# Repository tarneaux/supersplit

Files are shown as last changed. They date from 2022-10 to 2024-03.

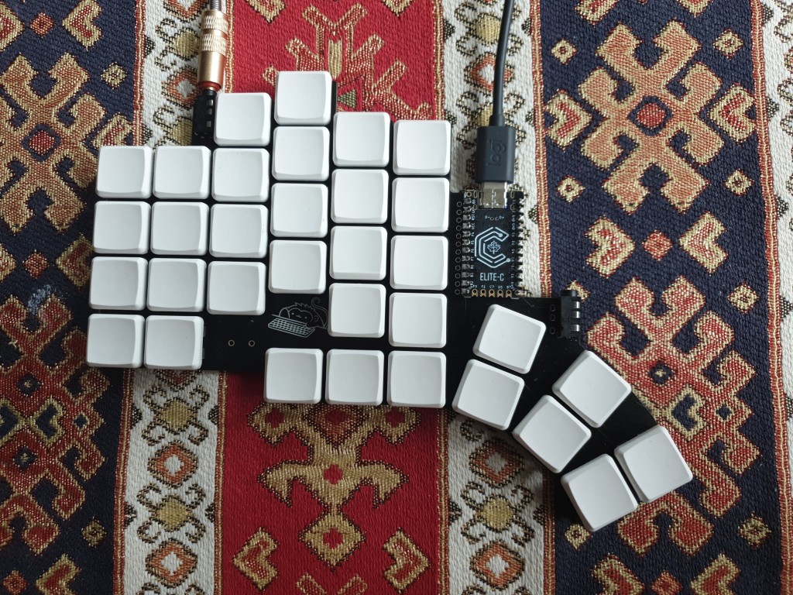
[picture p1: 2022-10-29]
photo.jpg

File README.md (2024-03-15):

# supersplit

You can read the article about this [here](https://tarneo.fr/posts/split_keyboard).

## What is this?
I tried to make a keyboard that is easy to use and compact. For this it has an (oversized) 9-key thumbfan and a (non-oversized) 4x6 matrix.

the entire keyboard

## Features
- 9-key thumbfan
- 4x6 matrix
- 2 trrs jacks on each side (four in total) for flexibility: on each side you can choose which one to use
- 2 elite-c controllers -> usb-c

## Downsides of this layout
As soon as I had soldered the keyboard, I noticed that the 4 outer thumb keys (On the right on the picture) were hard to reach and I am still not using them after a month of using this keyboard.
The 2 that are just next to the thumb home (the next 2 on the left of the previous) are easier to use but I prefer to use the 2 inner.
In short, that means I could have saved 6 keys on each side's thumfan.

## What I would do differently
I would let the matrix as is, remove the 4 outer thumfan keys and add a few degrees to the angle added to the next 2.

## Disclaimer

This was my first attempt at making my own PCB based split keyboard. The result didn't turn out great for this one, but I made a new keyboard I find much better to use, the [Triboard](https://github.com/tarneaux/triboard).

This keyboard has far too many keys on the thumbfan: the three keys below the matrix are easy to reach, but others are not: you could train your muscles to reach for the one a bit more to the middle, but the five others are just superfluous. If you really want that many keys in a keyboard:
- You don't need that many keys. They are useless. Really.
- If you still want a keywell so large, at least put it closer to your wrist and increase the angle compared to the keyboard. Then, use MX switches instead of choc ones to make the outer key well easier to reach.

You have been warned.

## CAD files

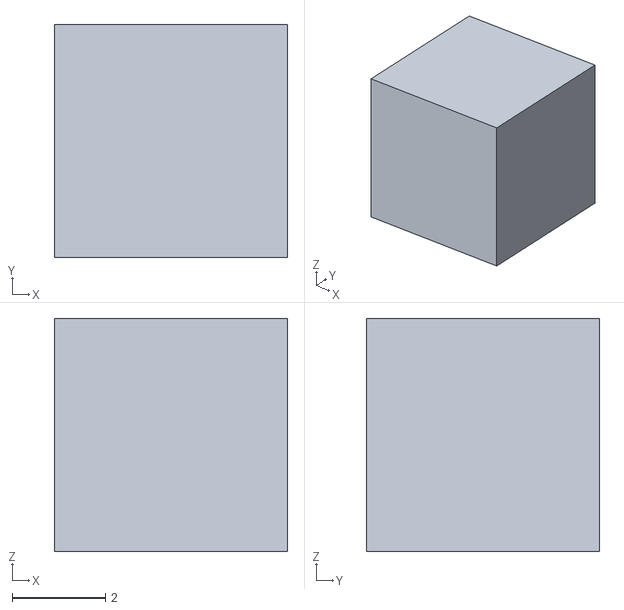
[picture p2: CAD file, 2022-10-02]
ergogen/test/cases/001_cube___cases_cube_stl.stl
5.00 x 5.00 x 5.00

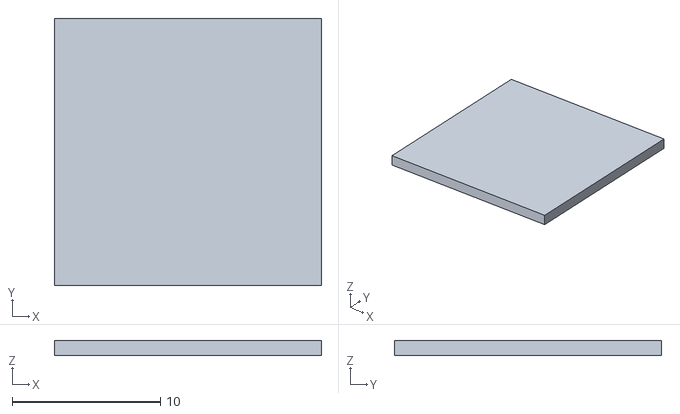
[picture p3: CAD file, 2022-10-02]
ergogen/test/cli/big/reference/cases/_export.stl
18.0 x 18.0 x 1.00

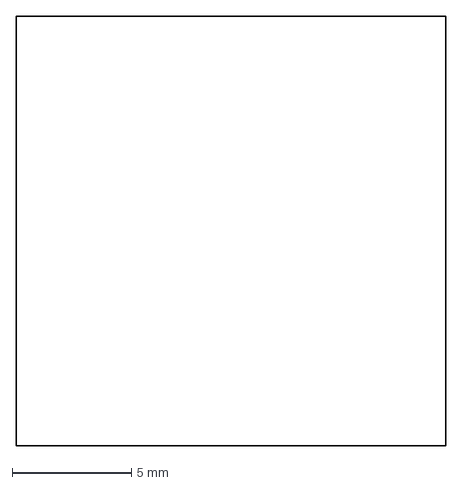
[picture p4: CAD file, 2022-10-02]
ergogen/test/cli/big/reference/outlines/_export.dxf
18.0 x 18.0 mm

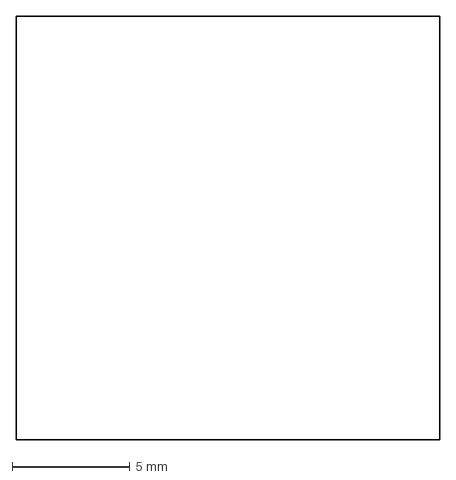
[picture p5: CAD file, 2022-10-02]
ergogen/test/cli/big/reference/points/demo.dxf
18.0 x 18.0 mm

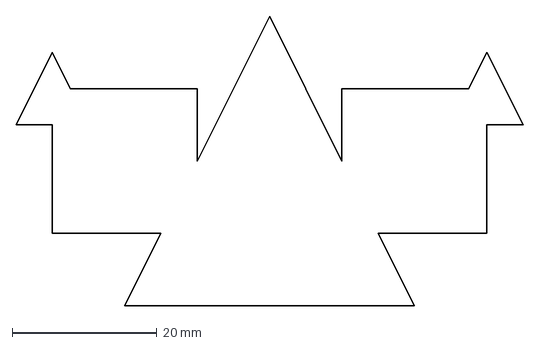
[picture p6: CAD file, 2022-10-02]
ergogen/test/outlines/polygons___outlines_outline_dxf.dxf
70.0 x 40.0 mm

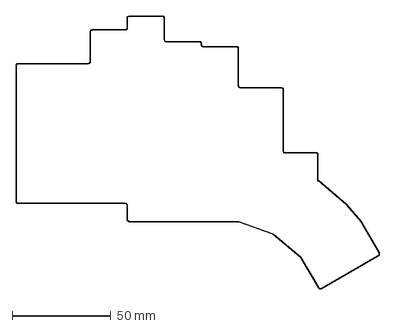
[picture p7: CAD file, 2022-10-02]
output/outlines/pcb.dxf
183.8 x 138.0 mm

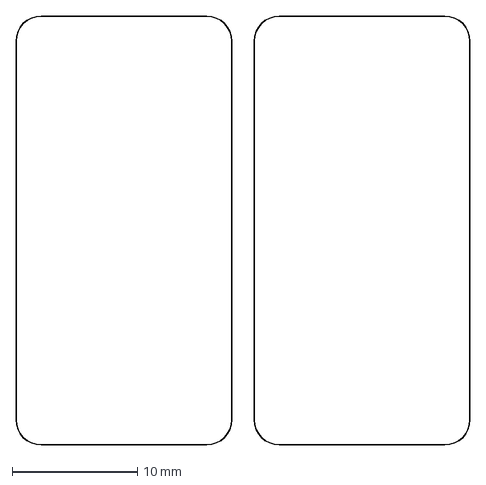
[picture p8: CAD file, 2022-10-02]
ergogen/test/outlines/fillet___outlines_fillet_dxf.dxf
36.2 x 34.2 mm

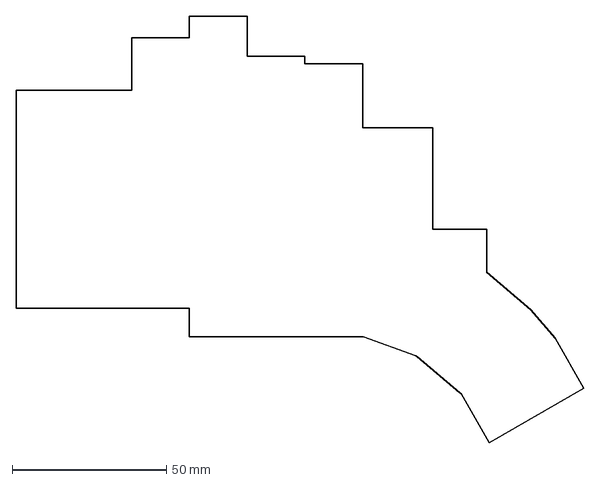
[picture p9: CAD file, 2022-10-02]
output/outlines/outline.dxf
184.0 x 138.3 mm

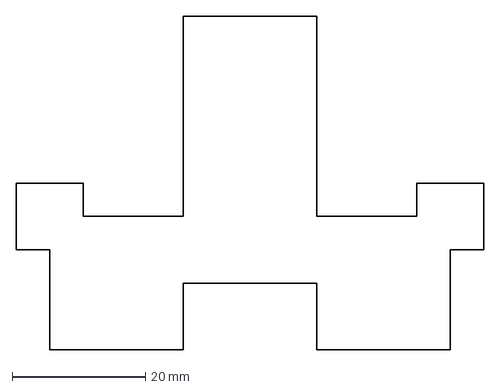
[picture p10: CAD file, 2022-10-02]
ergogen/test/outlines/rectangles___outlines_outline_dxf.dxf
70.0 x 50.0 mm

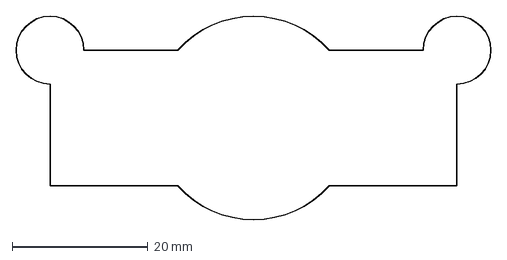
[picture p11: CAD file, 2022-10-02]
ergogen/test/outlines/circles___outlines_outline_dxf.dxf
70.0 x 30.0 mm

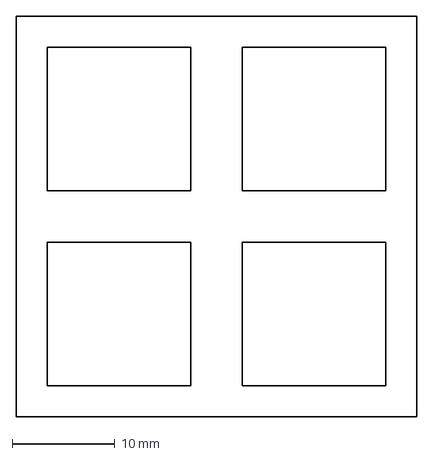
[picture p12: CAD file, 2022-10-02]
ergogen/test/outlines/basic___outlines_outline_dxf.dxf
39.0 x 39.0 mm

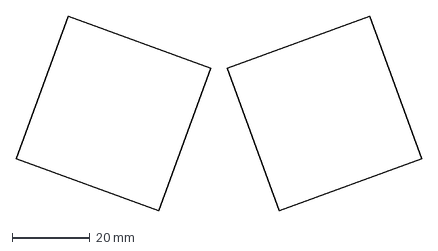
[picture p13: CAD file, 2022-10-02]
ergogen/test/outlines/gluing___outlines_optout_dxf.dxf
104.3 x 50.0 mm

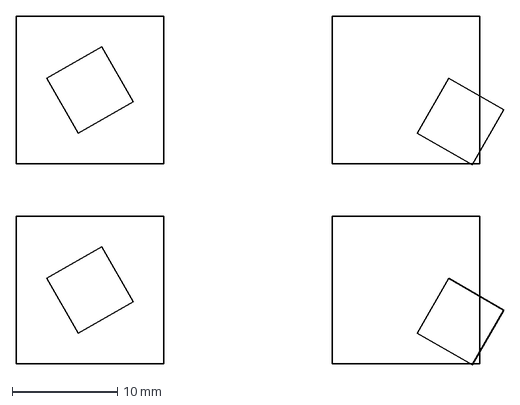
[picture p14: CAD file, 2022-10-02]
ergogen/test/outlines/affect_mirror___outlines_test_dxf.dxf
46.3 x 33.1 mm

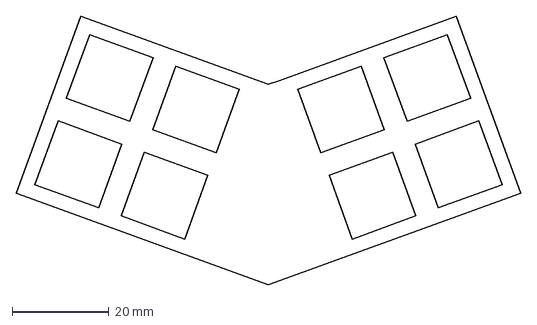
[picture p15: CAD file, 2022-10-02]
ergogen/test/outlines/gluing___outlines_outline_dxf.dxf
104.3 x 55.6 mm

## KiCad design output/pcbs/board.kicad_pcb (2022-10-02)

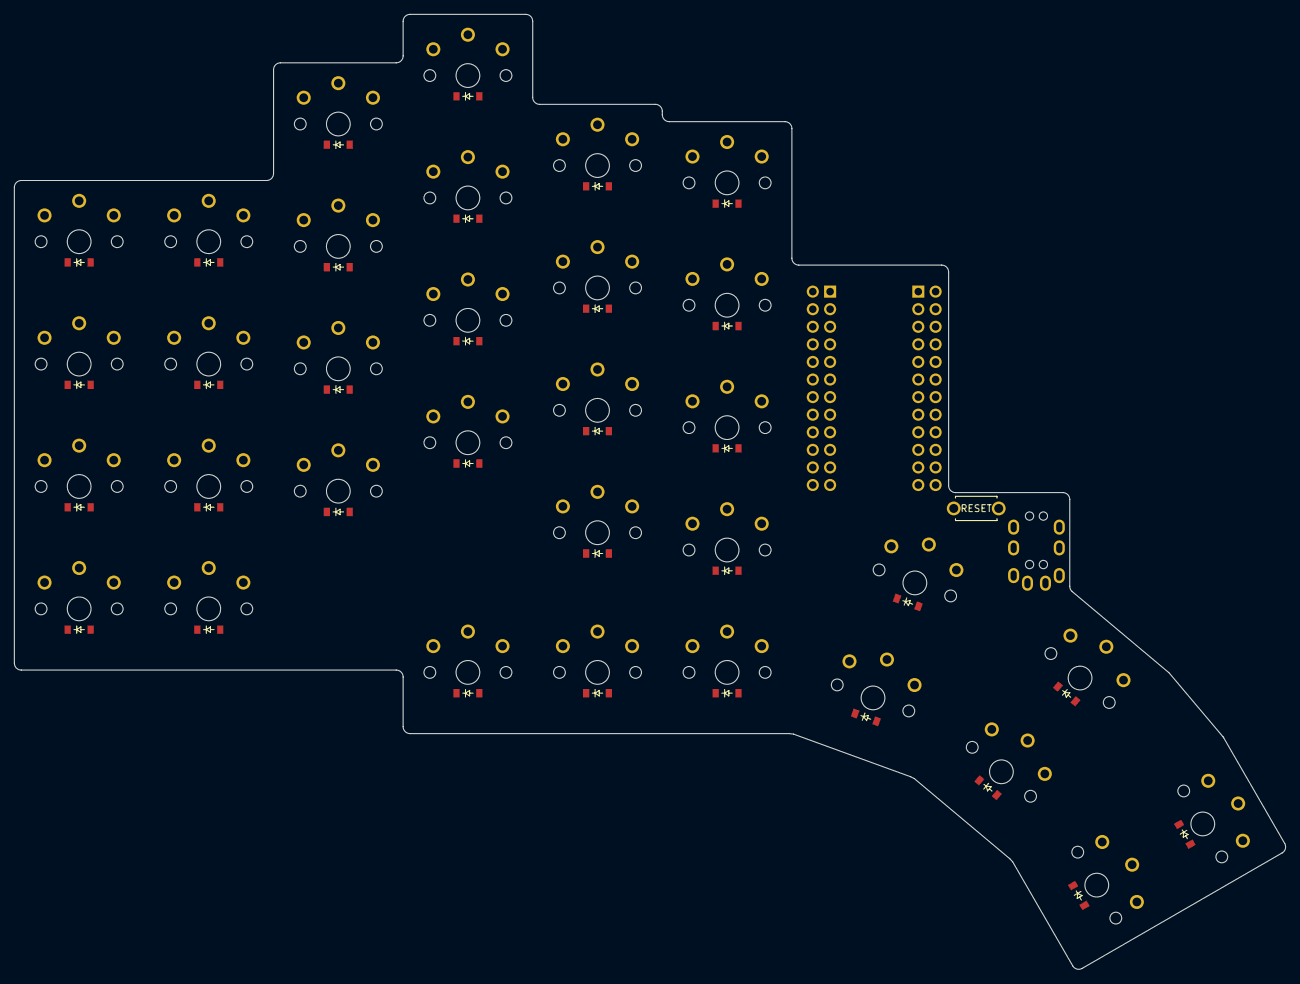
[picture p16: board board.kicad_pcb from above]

Board: 2 copper layers, 183.6 x 137.9 mm, 71 parts (0 on the bottom side), 55 nets, no tracks yet.

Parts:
B1: ResetSW
D1, D2, D3, D4, D5, D6, D7, D8, D9, D10, D11, D12, D13, D14, D15, D16, D17, D18, D19, D20, D21, D22, D23, D24, D25, D26, D27, D28, D29, D30, D31, D32, D33: ComboDiode
MCU1, MCU2: ProMicro
S1, S2, S3, S4, S5, S6, S7, S8, S9, S10, S11, S12, S13, S14, S15, S16, S17, S18, S19, S20, S21, S22, S23, S24, S25, S26, S27, S28, S29, S30, S31, S32, S33: PG1350
TRRS1, TRRS2: TRRS-PJ-320A-dual

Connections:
GND: B1.2, MCU1.2, MCU1.15, MCU1.16, MCU2.2, MCU2.15, MCU2.16, TRRS1.3, TRRS2.3
P0: MCU1.14, MCU2.14, TRRS1.4, TRRS2.4
P1: MCU1.13, MCU2.13
P2: D4.1, D8.1, D12.1, D16.1, D20.1, D24.1, MCU1.17, MCU2.17
P3: D3.1, D7.1, D11.1, D15.1, D19.1, D23.1, MCU1.18, MCU2.18
P4: D2.1, D6.1, D10.1, D14.1, D18.1, D22.1, MCU1.19, MCU2.19
P5: D1.1, D5.1, D9.1, D13.1, D17.1, D21.1, MCU1.20, MCU2.20
P6: D29.1, D31.1, D33.1, MCU1.21, MCU2.21
P7: D25.1, D26.1, D27.1, D28.1, D30.1, D32.1, MCU1.22, MCU2.22
P8: MCU1.23, MCU2.23
P9: MCU1.24, MCU2.24
P10: MCU1.12, MCU2.12, S1.2, S2.2, S3.2, S4.2, S25.2
P14: MCU1.10, MCU2.10, S9.2, S10.2, S11.2, S12.2, S27.2
P15: MCU1.9, MCU2.9, S13.2, S14.2, S15.2, S16.2, S28.2, S29.2
P16: MCU1.11, MCU2.11, S5.2, S6.2, S7.2, S8.2, S26.2
P18: MCU1.8, MCU2.8, S17.2, S18.2, S19.2, S20.2, S30.2, S31.2
P19: MCU1.7, MCU2.7, S21.2, S22.2, S23.2, S24.2, S32.2, S33.2
P20: MCU1.6, MCU2.6
P21: MCU1.5, MCU2.5
RAW: MCU1.1, MCU2.1
RST: B1.1, MCU1.3, MCU2.3
VCC: MCU1.4, MCU2.4, TRRS1.1, TRRS2.1
far_over: D29.2, S29.1
far_thumb: D28.2, S28.1
farther_over: D31.2, S31.1
farther_thumb: D30.2, S30.1
home_thumb: D27.2, S27.1
index_bottom: D17.2, S17.1
index_home: D18.2, S18.1
index_over: D20.2, S20.1
index_top: D19.2, S19.1
inner_bottom: D21.2, S21.1
inner_home: D22.2, S22.1
inner_over: D24.2, S24.1
inner_thumb: D25.2, S25.1
inner_top: D23.2, S23.1
middle_bottom: D13.2, S13.1
middle_home: D14.2, S14.1
middle_over: D16.2, S16.1
middle_top: D15.2, S15.1
near_thumb: D26.2, S26.1
outer_over: D33.2, S33.1
outer_thumb: D32.2, S32.1
pinky_bottom: D5.2, S5.1
pinky_home: D6.2, S6.1
pinky_off_bottom: D1.2, S1.1
pinky_off_home: D2.2, S2.1
pinky_off_over: D4.2, S4.1
pinky_off_top: D3.2, S3.1
pinky_over: D8.2, S8.1
pinky_top: D7.2, S7.1
ring_bottom: D9.2, S9.1
ring_home: D10.2, S10.1
ring_over: D12.2, S12.1
ring_top: D11.2, S11.1

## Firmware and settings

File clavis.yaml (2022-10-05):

units:
  kx: cx
  ky: cy
  px: 2
  py: 2
  mcu_y_offset: -10
  #mcu_y_offset: 10

points:
  key:
    footprints:
      choc_solder:
        type: choc
        # TODO: right orientation for normal and home keys?
        #anchor:
          #rotate: 180
        params:
          reverse: true
          keycaps: true
        nets:
          # from: P1
          # to: P2
          from: =colrow
          to: =column_net
      diode:
        type: diode
        nets:
          from: =colrow
          to: =row_net
        anchor:
          rotate: 0
          shift: [0, -4.7]
  zones:
    matrix:
      key.padding: 1.04 ky
      columns:
        pinky_off:
          stagger: 0 ky
          spread: 1kx
          key:
            column_net: P10
        pinky:
          stagger: 0 ky
          spread: 1.04 kx
          key:
            column_net: P16
        ring:
          stagger: 17
          spread: 1.04kx
          key:
            column_net: P14
        middle:
          stagger: 7
          spread: 1.04kx
          key:
            column_net: P15
        index:
          stagger: -13
          spread: 1.04kx
          rotate: -0
          key:
            column_net: P18
        inner:
          stagger: -2.5
          spread: 1.04kx
          key:
            column_net: P19
      rows:
        bottom:
          row_net: P5
        home:
          row_net: P4
        top:
          row_net: P3
        over:
          row_net: P2
    thumbfan:
      key.padding: 1.04 ky
      anchor:
        ref: matrix_inner_bottom
        shift: [-2.08 kx, -1.04 ky]
      columns:
        inner:
          key:
            column_net: P10
        near:
          spread: 1.04 kx
          key:
            column_net: P16
        home:
          spread: 1.04 kx
          key:
            column_net: P14
        far:
          # Calculated with pythagoras's theorem
          spread: 1.039658 kx
          stagger: -0.005221 kx
          rotate: -20
          origin: [-0.5 kx, -0.5 ky]
          key:
            column_net: P15
          row_overrides:
            thumb:
              row_net: P7
            over: 
              row_net: P6
        farther:
          $extends: points.zones.thumbfan.columns.far
          key:
            column_net: P18
        outer:
          $extends: points.zones.thumbfan.columns.far
          key:
            column_net: P19
      rows:
        thumb:
          row_net: P7
outlines:
  exports:
    outline:
      # Matrix
      - type: polygon
        points:
          - ref: matrix_pinky_off_over
            shift: [-0.52 kx, 0.52 ky]
          - ref: matrix_pinky_off_bottom
            shift: [-0.52 kx, -0.52 ky]
          - ref: matrix_pinky_bottom
            shift: [3 kx, -0.52 ky]
          - ref: matrix_inner_bottom
            shift: [0.52 kx, -0.52 ky]
          - ref: matrix_inner_over
            shift: [0.52 kx, 0.52 ky]
          - ref: matrix_inner_over
            shift: [-0.52 kx, 0.52 ky]
          - ref: matrix_index_over
            shift: [0.52 kx, 0.52 ky]
          - ref: matrix_index_over
            shift: [-0.52 kx, 0.52 ky]
          - ref: matrix_middle_over
            shift: [0.52 kx, 0.52 ky]
          - ref: matrix_middle_over
            shift: [-0.52 kx, 0.52 ky]
          - ref: matrix_ring_over
            shift: [0.52 kx, 0.52 ky]
          - ref: matrix_ring_over
            shift: [-0.52 kx, 0.52 ky]
          - ref: matrix_pinky_over
            shift: [0.52 kx, 0.52 ky]
          - ref: matrix_pinky_over
            shift: [-0.52 kx, 0.52 ky]
          - ref: matrix_pinky_off_over
            shift: [0.52 kx, 0.52 ky]
      # Thumbfan
      - type: polygon
        points:
          - ref: thumbfan_far_over
            shift: [0.52 kx, 0.52 ky]
          - ref: thumbfan_farther_over
            shift: [-0.52 kx, 0.52 ky]
          - ref: thumbfan_farther_over
            shift: [0.52 kx, 0.52 ky]
          - ref: thumbfan_outer_over
            shift: [-0.52 kx, 0.52 ky]
          - ref: thumbfan_outer_over
            shift: [0.52 kx, 0.52 ky]
          - ref: thumbfan_outer_thumb
            shift: [0.52 kx, -0.52 ky]
          - ref: thumbfan_outer_thumb
            shift: [-0.5 kx, -0.52 ky]
          - ref: thumbfan_farther_thumb
            shift: [0.5 kx, -0.52 ky]
          - ref: thumbfan_farther_thumb
            shift: [-0.5 kx, -0.52 ky]
          - ref: thumbfan_far_thumb
            shift: [0.5 kx, -0.52 ky]
          - ref: thumbfan_far_thumb
            shift: [-0.5 kx, -0.52 ky]
          - ref: thumbfan_home_thumb
            shift: [0.5 kx, -0.52 ky]
          - ref: thumbfan_home_thumb
            shift: [-0.5 kx, -0.52 ky]
          - ref: thumbfan_near_thumb
            shift: [0.5 kx, -0.52 ky]
          - ref: thumbfan_near_thumb
            shift: [-0.5 kx, -0.52 ky]
          - ref: thumbfan_inner_thumb
            shift: [-0.52 kx, -0.52 ky]
          - ref: thumbfan_inner_thumb
            shift: [-0.52 kx, 0.52 ky]
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
